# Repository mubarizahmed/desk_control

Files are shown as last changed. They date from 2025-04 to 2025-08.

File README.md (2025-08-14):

# desk-control

This is a simple physical widget that sits on your desk and allows you to perform some basic productivity tasks. It works independently of your computer or phone and hence, _in theory_, it should help you focus on your work. It is a work in progress and I will be adding more features as I go along.

<div align="center" style="display: flex; justify-content: center; align-items: center;">
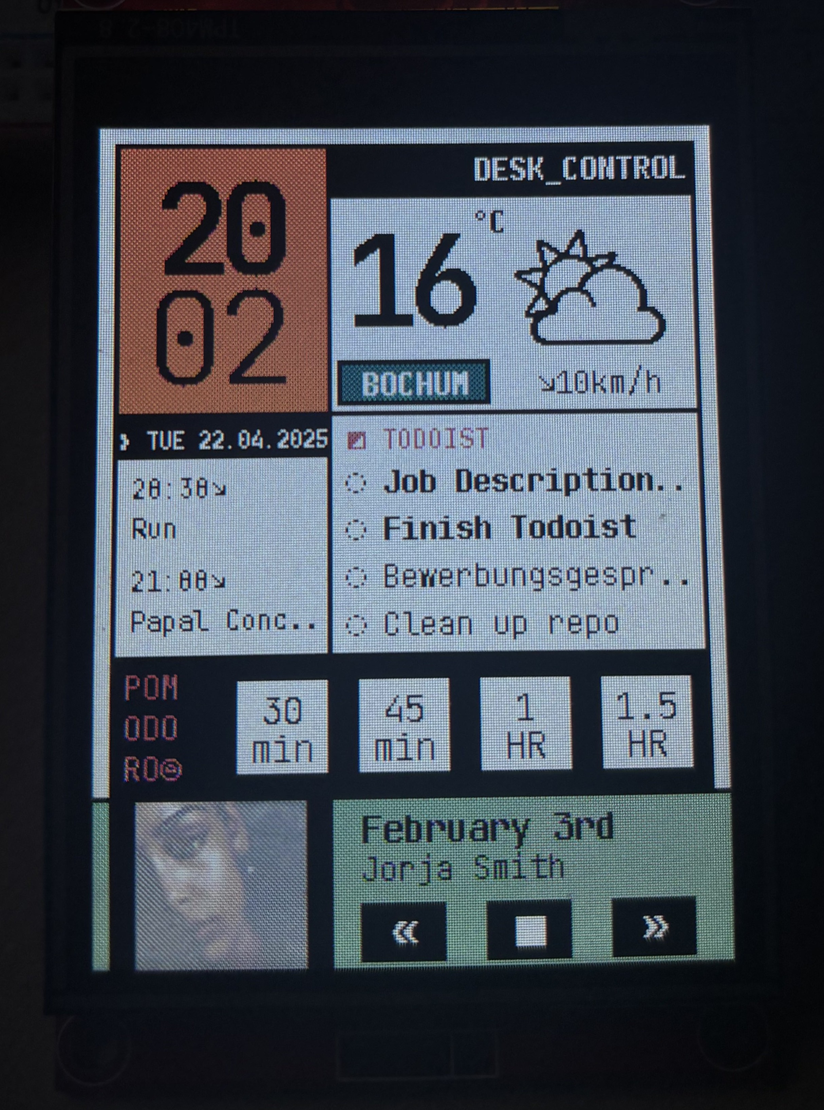
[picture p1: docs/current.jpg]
Actual UI
  
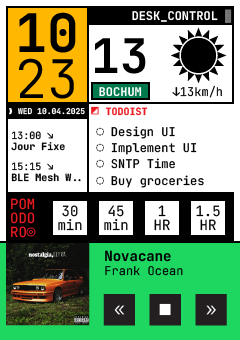
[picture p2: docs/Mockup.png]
Mock UI
  
</div>

## Features

- **Current Time** - Displays the current time in a 24-hour format.
- **Weather** - Displays the current temperature, wind, and weather condition (sunny, cloudy, etc.) for a given location.
- **Pomodoro Timer** - A simple timer that helps you focus on your work for a some template amount of time and then take a break. Current implementation is 25 minutes of work and 5 minutes of break. You can change this in the code.
- **Calendar** - Displays the current date and the next 2 events from your Google Calendar. You need to set up a Google script to get the events from your calendar. See the [Google Calendar Setup](#google-calendar-setup) section below.

- **Spotify Control** - Control your Spotify playback (play, pause, next, previous) from the widget.

- **Todoist Integration** - View and complete your upcoming tasks from Todoist.

- **PCB Design** - Single PCB design that can be printed on PCBWay or JLCPCB.

## Planned Features

- **Housing** - 3D printed housing for the PCB and screen.

- **Sensor Integration** - Add more sensors to the project - maybe a temperature sensor, humidity sensor, etc. to get more data from the environment.

- **Widget Details** - Widgets will be clickable and will show more details about the current state. For example, the weather widget will show the hourly forecast for the next 24 hours, the calendar widget will show the events for the next week, etc.

## Hardware Setup (Work in Progress)

The hardware setup is a work in progress. I will be updating this section as I go along. Currently, the hardware setup is:

- **Microcontroller** - ESP32-DevKitC-v4
- **Display** - 2.4" TFT LCD (ILI9341) with SPI interface
- **Rotary Encoder** - KY-040 rotary encoder with push button.

A custom PCB has been designed but not yet tested. The schematic and KiCAD project files are available in the `eda` folder.

<div align="center">
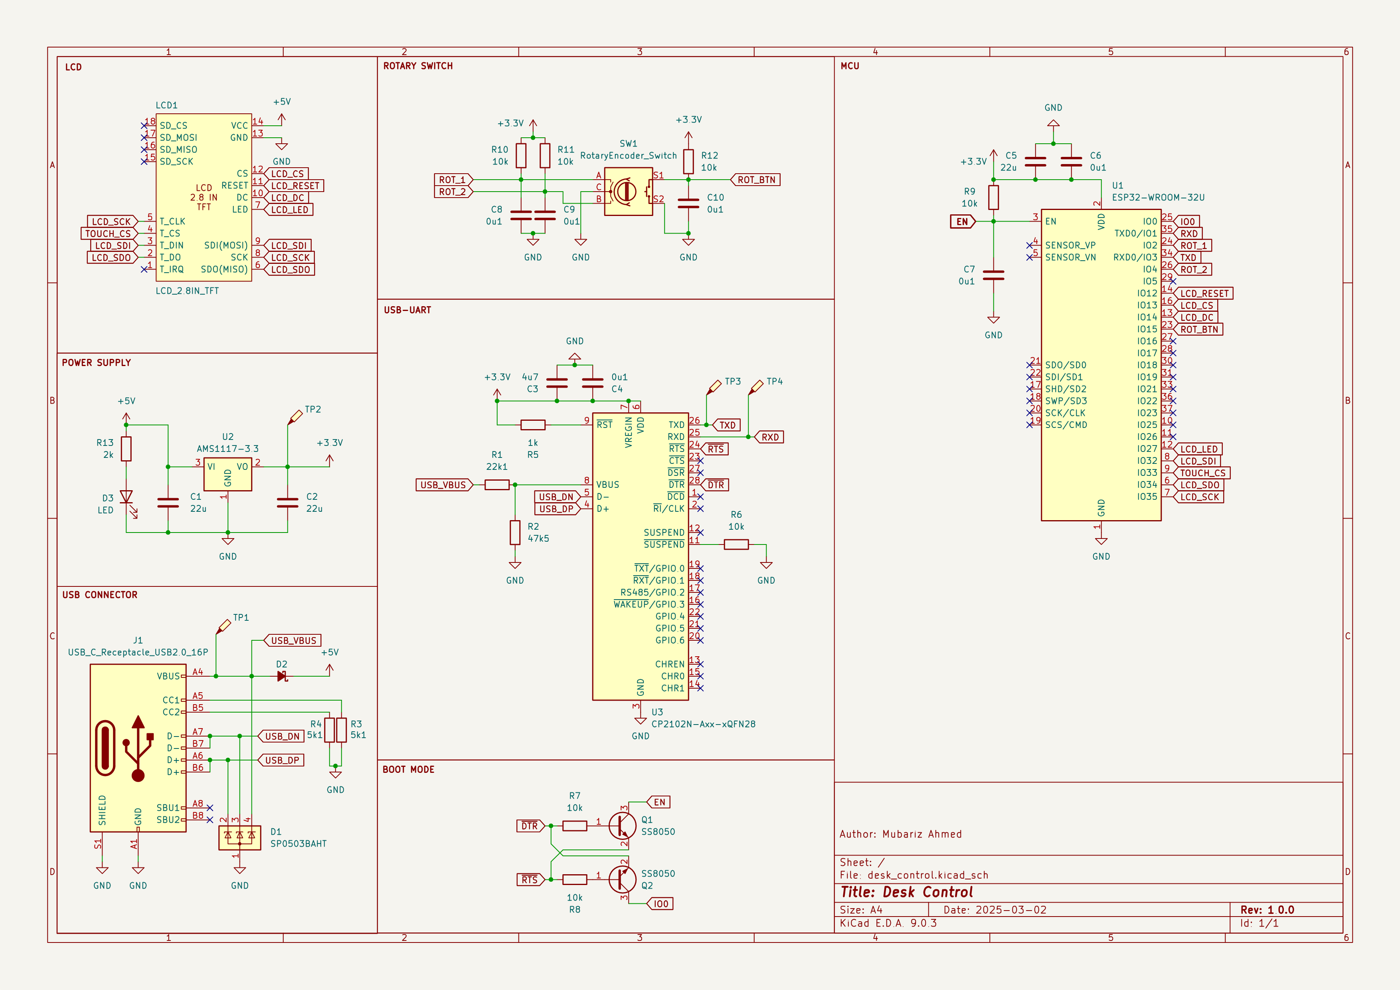
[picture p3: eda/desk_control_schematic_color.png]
Schematic
  
</div>

[Schematic](eda/desk_control_schematic_color.png)

<div align="center" style="display: flex; justify-content: center; align-items: center;">
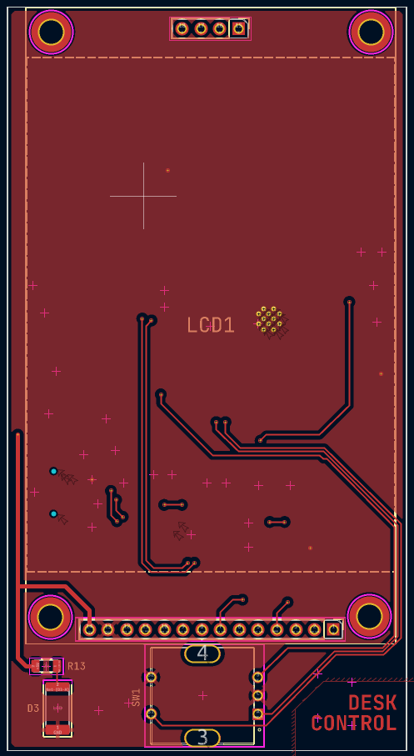
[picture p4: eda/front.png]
PCB Front
  
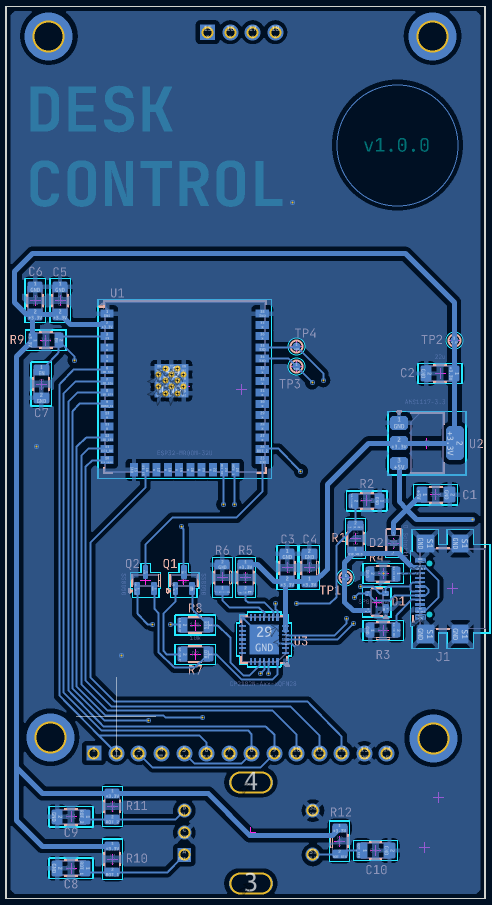
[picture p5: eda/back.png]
PCB Back
  
</div>

[PCB Front](eda/front.png) | [PCB Back](eda/back.png)

[KiCAD Project](eda/desk_control)

Pin definitions are given in [here](/main/pin_definitions.h).

## Software Setup

ESP IDF is used to program the ESP32. The project can be configured using `idf.py menuconfig`. The following configuration options are most relevant:

- **ESP_WIFI_SSID** - The SSID of the Wi-Fi network to connect to.
- **ESP_WIFI_PASSWORD** - The password of the Wi-Fi network to connect to.
- **CALENDAR_URL** - The URL of the Google script that returns the events from your calendar.

## Mock UI

The mock UI is a simple representation of what the final UI will look like. It is not a final design and will be updated as I go along. The current design is a simple grid layout with a monotype font which makes absolute positioning of the elements easy.

<div align="center">
  Mock UI
</div>

## Progress

The project is being prototyped on a breadboard and the hardware setup is a work in progress. The software is being developed in parallel. The current status of the project is shown below:

<div align="center">
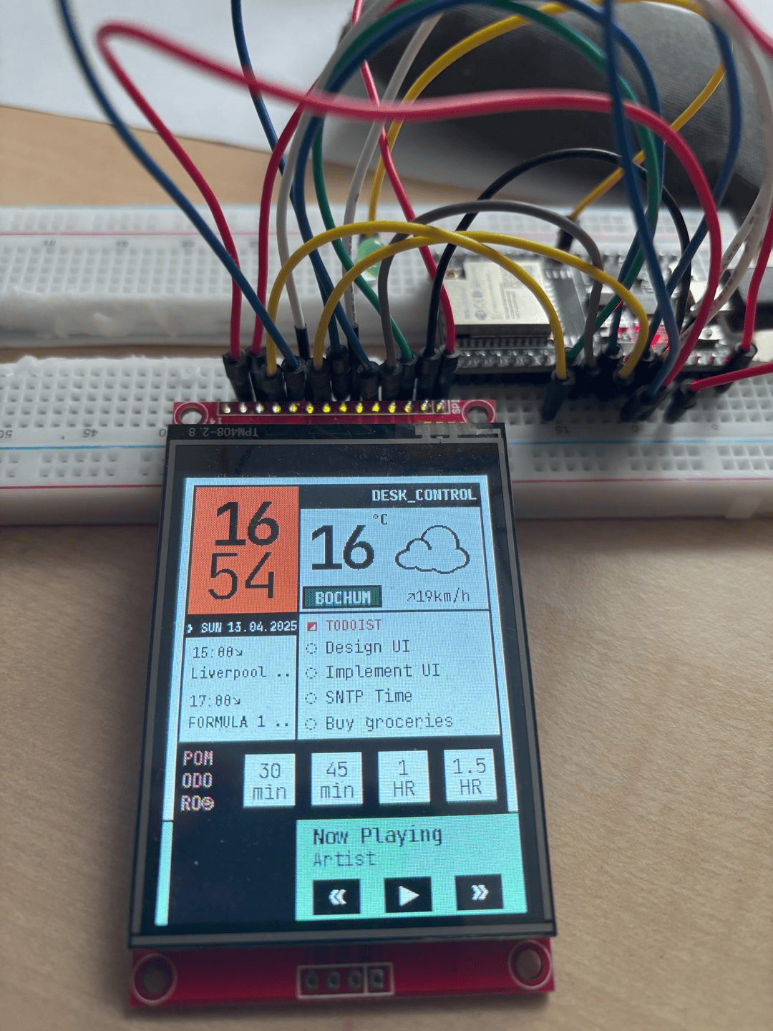
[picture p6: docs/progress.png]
Progress
  
</div>

## Google Calendar Setup

To get the events from your Google Calendar, you need to set up a Google script that will fetch the events and return them in a JSON format. The script should be deployed as a web app and the URL should be added to the code. The following steps will help you set up the Google script:

1. Go to [Google Apps Script](https://script.google.com/) and create a new project.
2. Copy and paste the code from this (file)[https://github.com/mubarizahmed/desk_control/blob/main/other/calendar.gs] into the script editor
3. Save the project and give it a name.
4. Click on the `Deploy` button and select `New deployment`.
5. Select `Web app` and give it a name.
6. Select `Anyone` under `Who has access` and click on `Deploy`.
7. Authorize the script to access your Google Calendar.
8. Copy the URL of the web app and paste it in the code where it says `CALENDAR_URL`.
9. Save the code and run the script to test it. You should see the events from your calendar in the JSON format.

Thanks to this [blog post](https://www.instructables.com/E-Ink-Family-Calendar-Using-ESP32/) for the idea and the code to get the events from the Google Calendar. The code has been modified to fit the needs of this project.

## Acknowledgements

Thanks to [wttr.in](https://wttr.in/) for the weather API and [Google Calendar API](https://developers.google.com/calendar) for the calendar API.

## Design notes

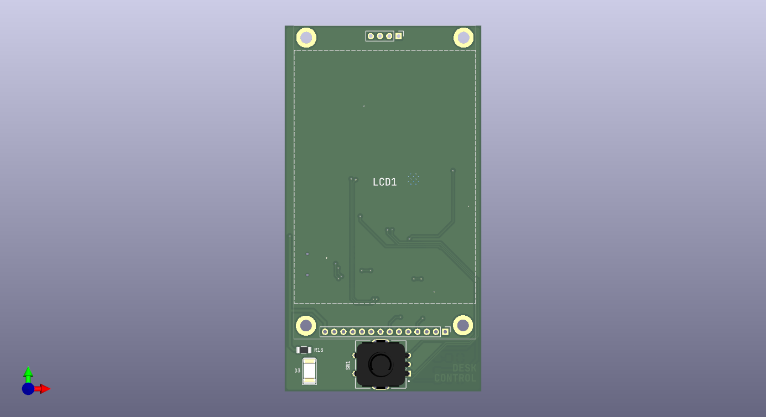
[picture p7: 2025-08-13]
eda/desk_control_f2.png

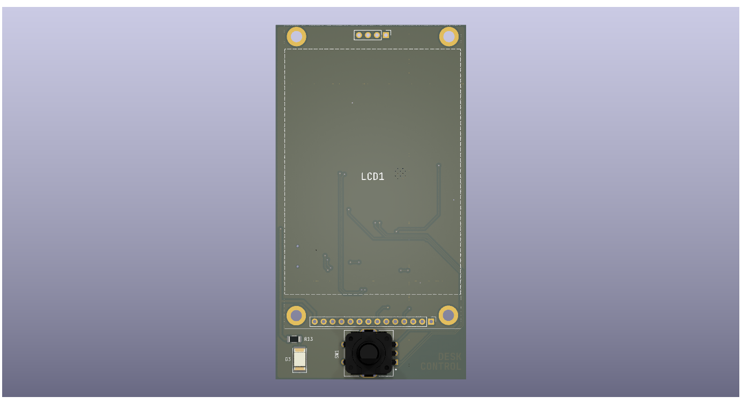
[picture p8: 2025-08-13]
eda/desk_control_f.png

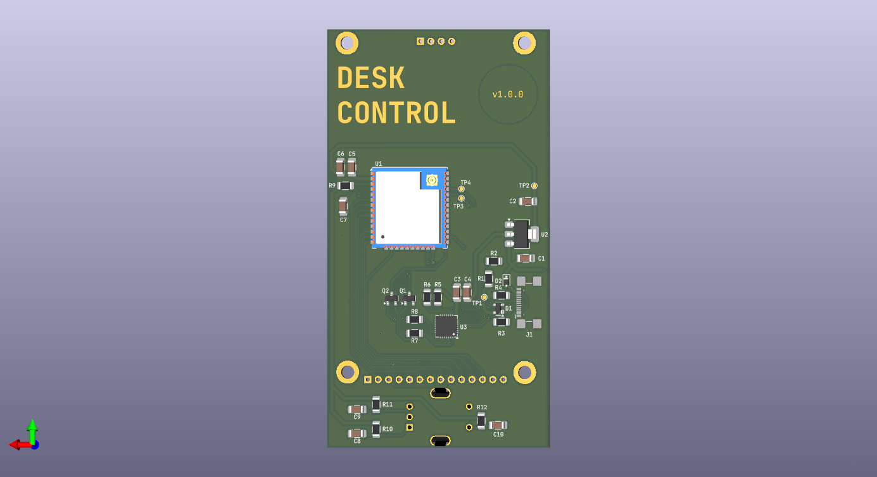
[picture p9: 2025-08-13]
eda/desk_control_b2.png

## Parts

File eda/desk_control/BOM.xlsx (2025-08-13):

Reference | Qty | Value | DNP | Exclude from BOM | Exclude from Board | Footprint | Datasheet
C1,C2,C5 | 3 | 22u |  |  |  | Capacitor_SMD:C_1206_3216Metric_Pad1.33x1.80mm_HandSolder | ~
C3 | 1 | 4u7 |  |  |  | Capacitor_SMD:C_1206_3216Metric_Pad1.33x1.80mm_HandSolder | ~
C4,C6,C7,C8,C9,C10 | 6 | 0u1 |  |  |  | Capacitor_SMD:C_1206_3216Metric_Pad1.33x1.80mm_HandSolder | ~
D1 | 1 | SP0503BAHT |  |  |  | Package_TO_SOT_SMD:SOT-143 | http://www.littelfuse.com/~/media/files/littelfuse/technical%20resources/documents/data%20sheets/sp05xxba.pdf
D2 | 1 | D_Schottky_Small_Filled |  |  |  | Diode_SMD:D_SOD-323F | ~
D3 | 1 | LED |  |  |  | LED_SMD:LED_2512_6332Metric | ~
J1 | 1 | USB_C_Receptacle_USB2.0_16P |  |  |  | Connector_USB:USB_C_Receptacle_GCT_USB4110 | https://www.usb.org/sites/default/files/documents/usb_type-c.zip
LCD1 | 1 | LCD_2.8IN_TFT |  |  |  | Custom:LCD_2.8_TFT
Q1,Q2 | 2 | SS8050 |  |  |  | Package_TO_SOT_SMD:SOT-23 | http://www.secosgmbh.com/datasheet/products/SSMPTransistor/SOT-23/SS8050.pdf
R1 | 1 | 22k1 |  |  |  | Resistor_SMD:R_1206_3216Metric | ~
R2 | 1 | 47k5 |  |  |  | Resistor_SMD:R_1206_3216Metric | ~
R3,R4 | 2 | 5k1 |  |  |  | Resistor_SMD:R_1206_3216Metric | ~
R5 | 1 | 1k |  |  |  | Resistor_SMD:R_1206_3216Metric | ~
R6,R7,R8,R9,R10,R11,R12 | 7 | 10k |  |  |  | Resistor_SMD:R_1206_3216Metric | ~
R13 | 1 | 2k |  |  |  | Resistor_SMD:R_1206_3216Metric | ~
SW1 | 1 | RotaryEncoder_Switch |  |  |  | Custom:Bourns-PEC11R-4220F-S0024-0-0-0 | ~
TP1,TP2,TP3,TP4 | 4 | TestPoint_Probe |  |  |  | TestPoint:TestPoint_Pad_D1.0mm | ~
U1 | 1 | ESP32-WROOM-32U |  |  |  | RF_Module:ESP32-WROOM-32U | https://www.espressif.com/sites/default/files/documentation/esp32-wroom-32d_esp32-wroom-32u_datasheet_en.pdf
U2 | 1 | AMS1117-3.3 |  |  |  | Package_TO_SOT_SMD:SOT-223-3_TabPin2 | http://www.advanced-monolithic.com/pdf/ds1117.pdf
U3 | 1 | CP2102N-Axx-xQFN28 |  |  |  | Package_DFN_QFN:QFN-28-1EP_5x5mm_P0.5mm_EP3.35x3.35mm | https://www.silabs.com/documents/public/data-sheets/cp2102n-datasheet.pdf

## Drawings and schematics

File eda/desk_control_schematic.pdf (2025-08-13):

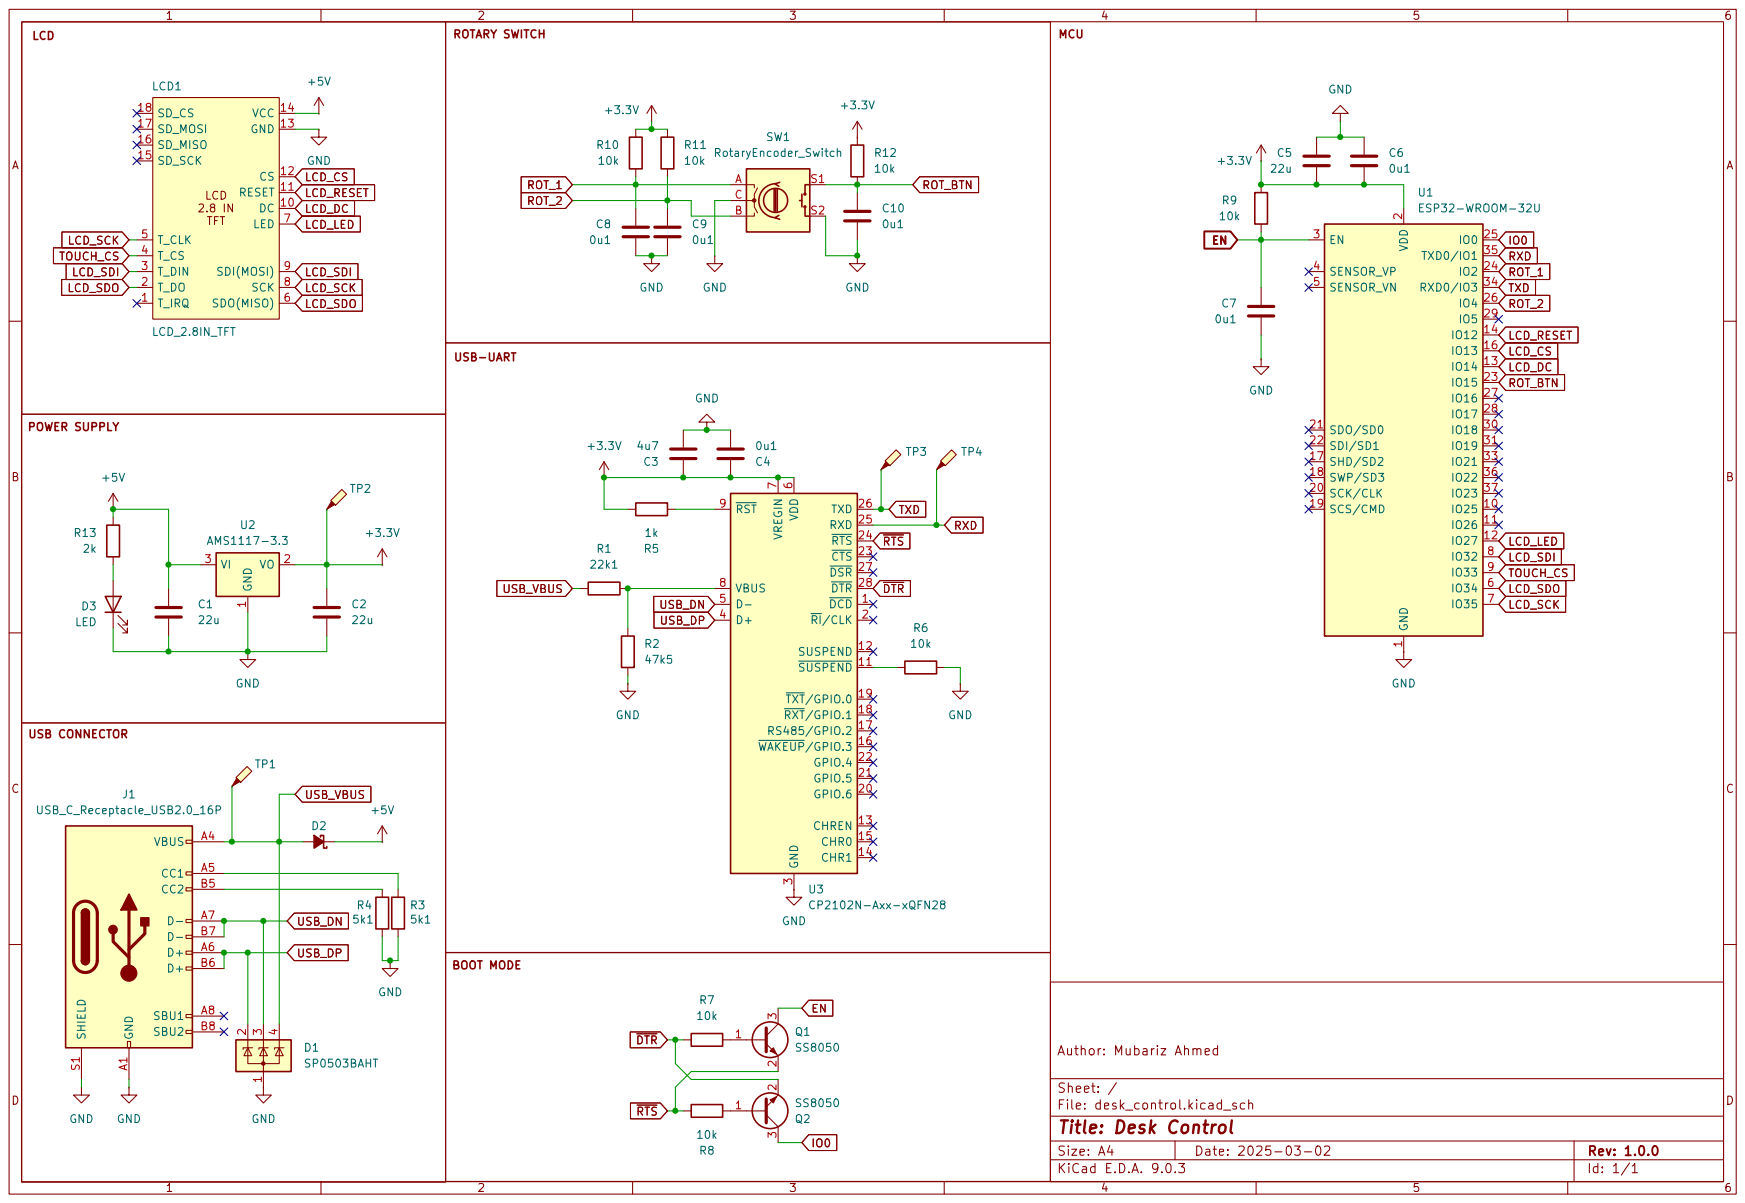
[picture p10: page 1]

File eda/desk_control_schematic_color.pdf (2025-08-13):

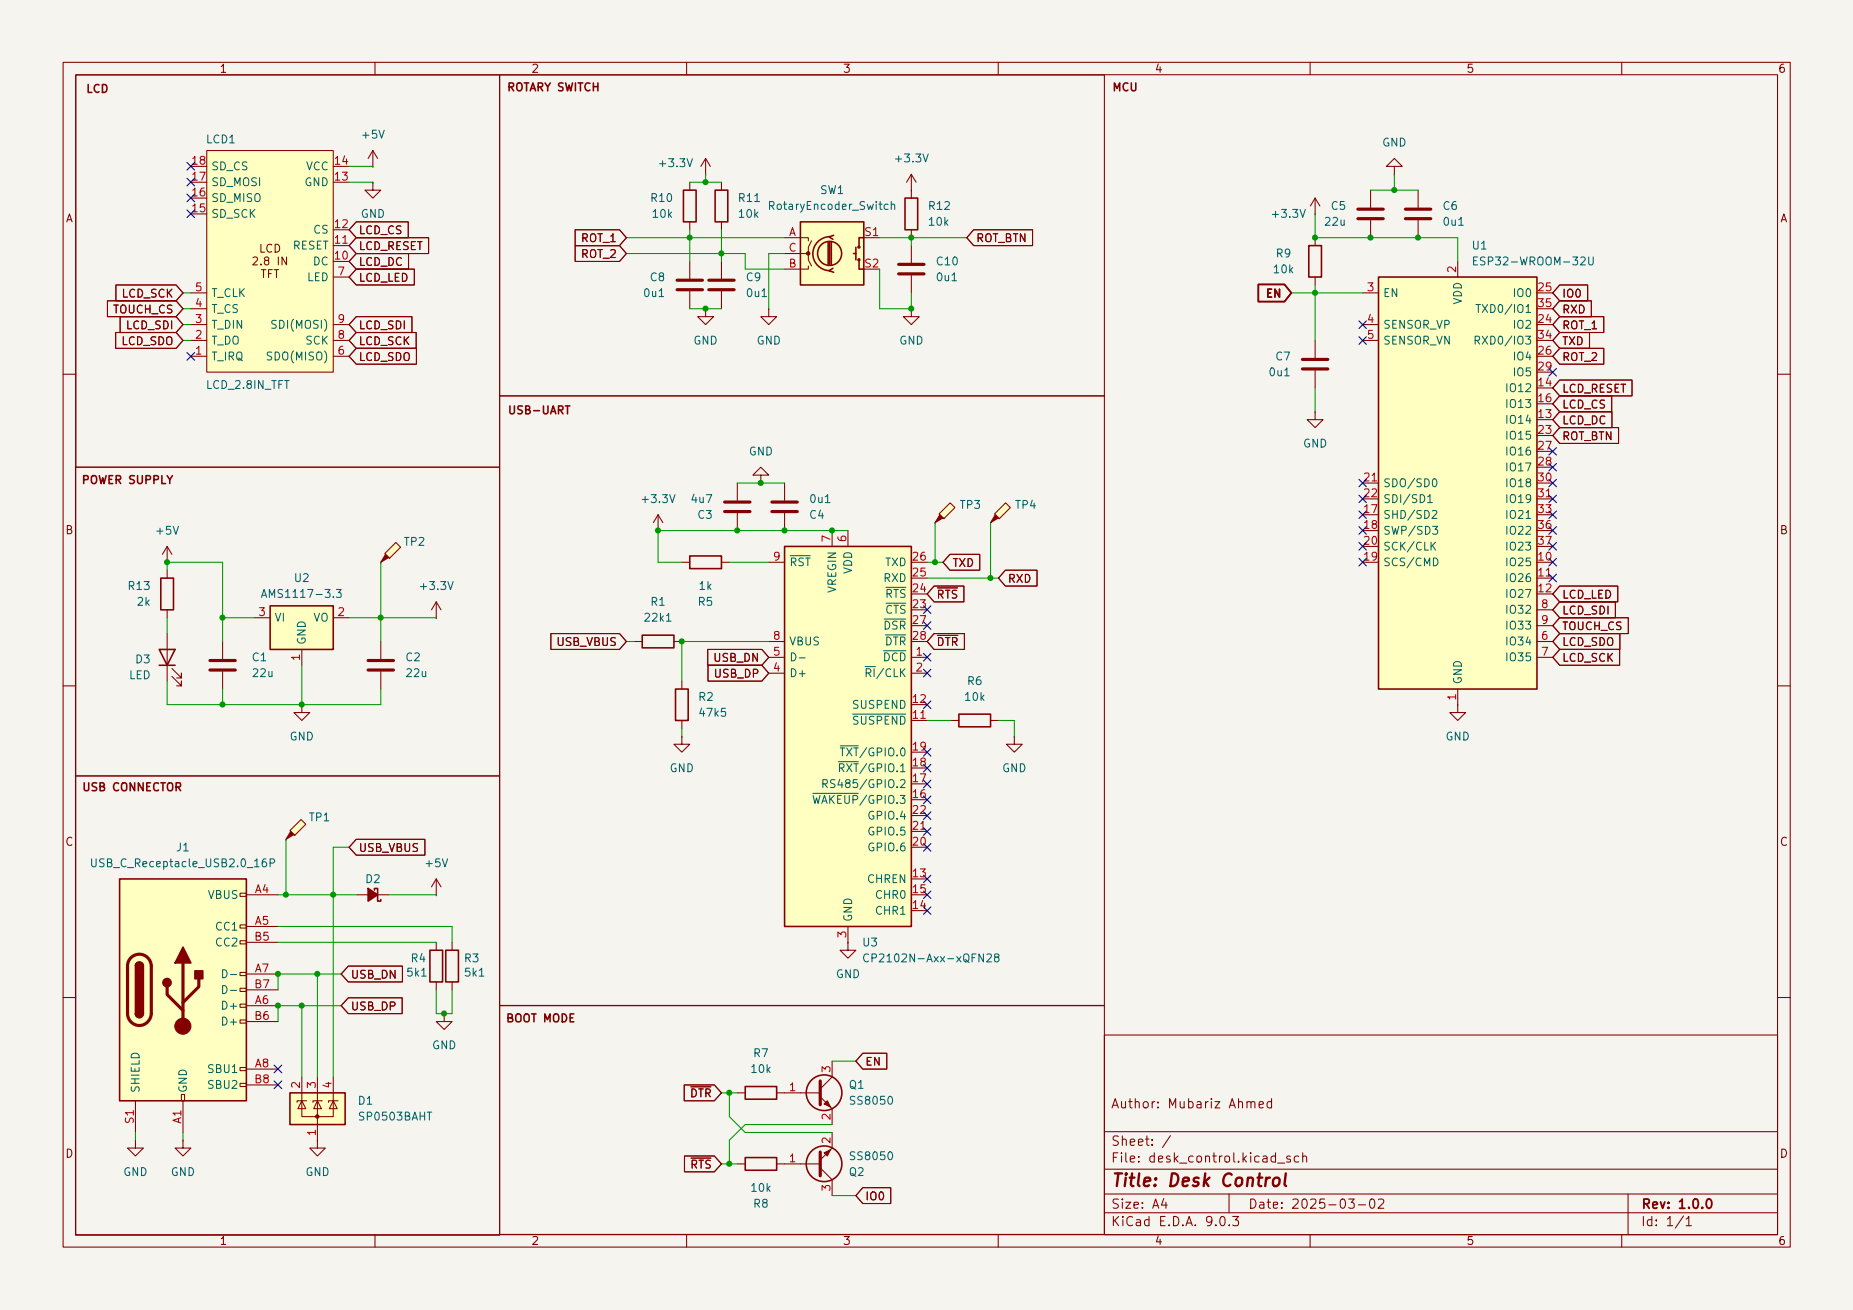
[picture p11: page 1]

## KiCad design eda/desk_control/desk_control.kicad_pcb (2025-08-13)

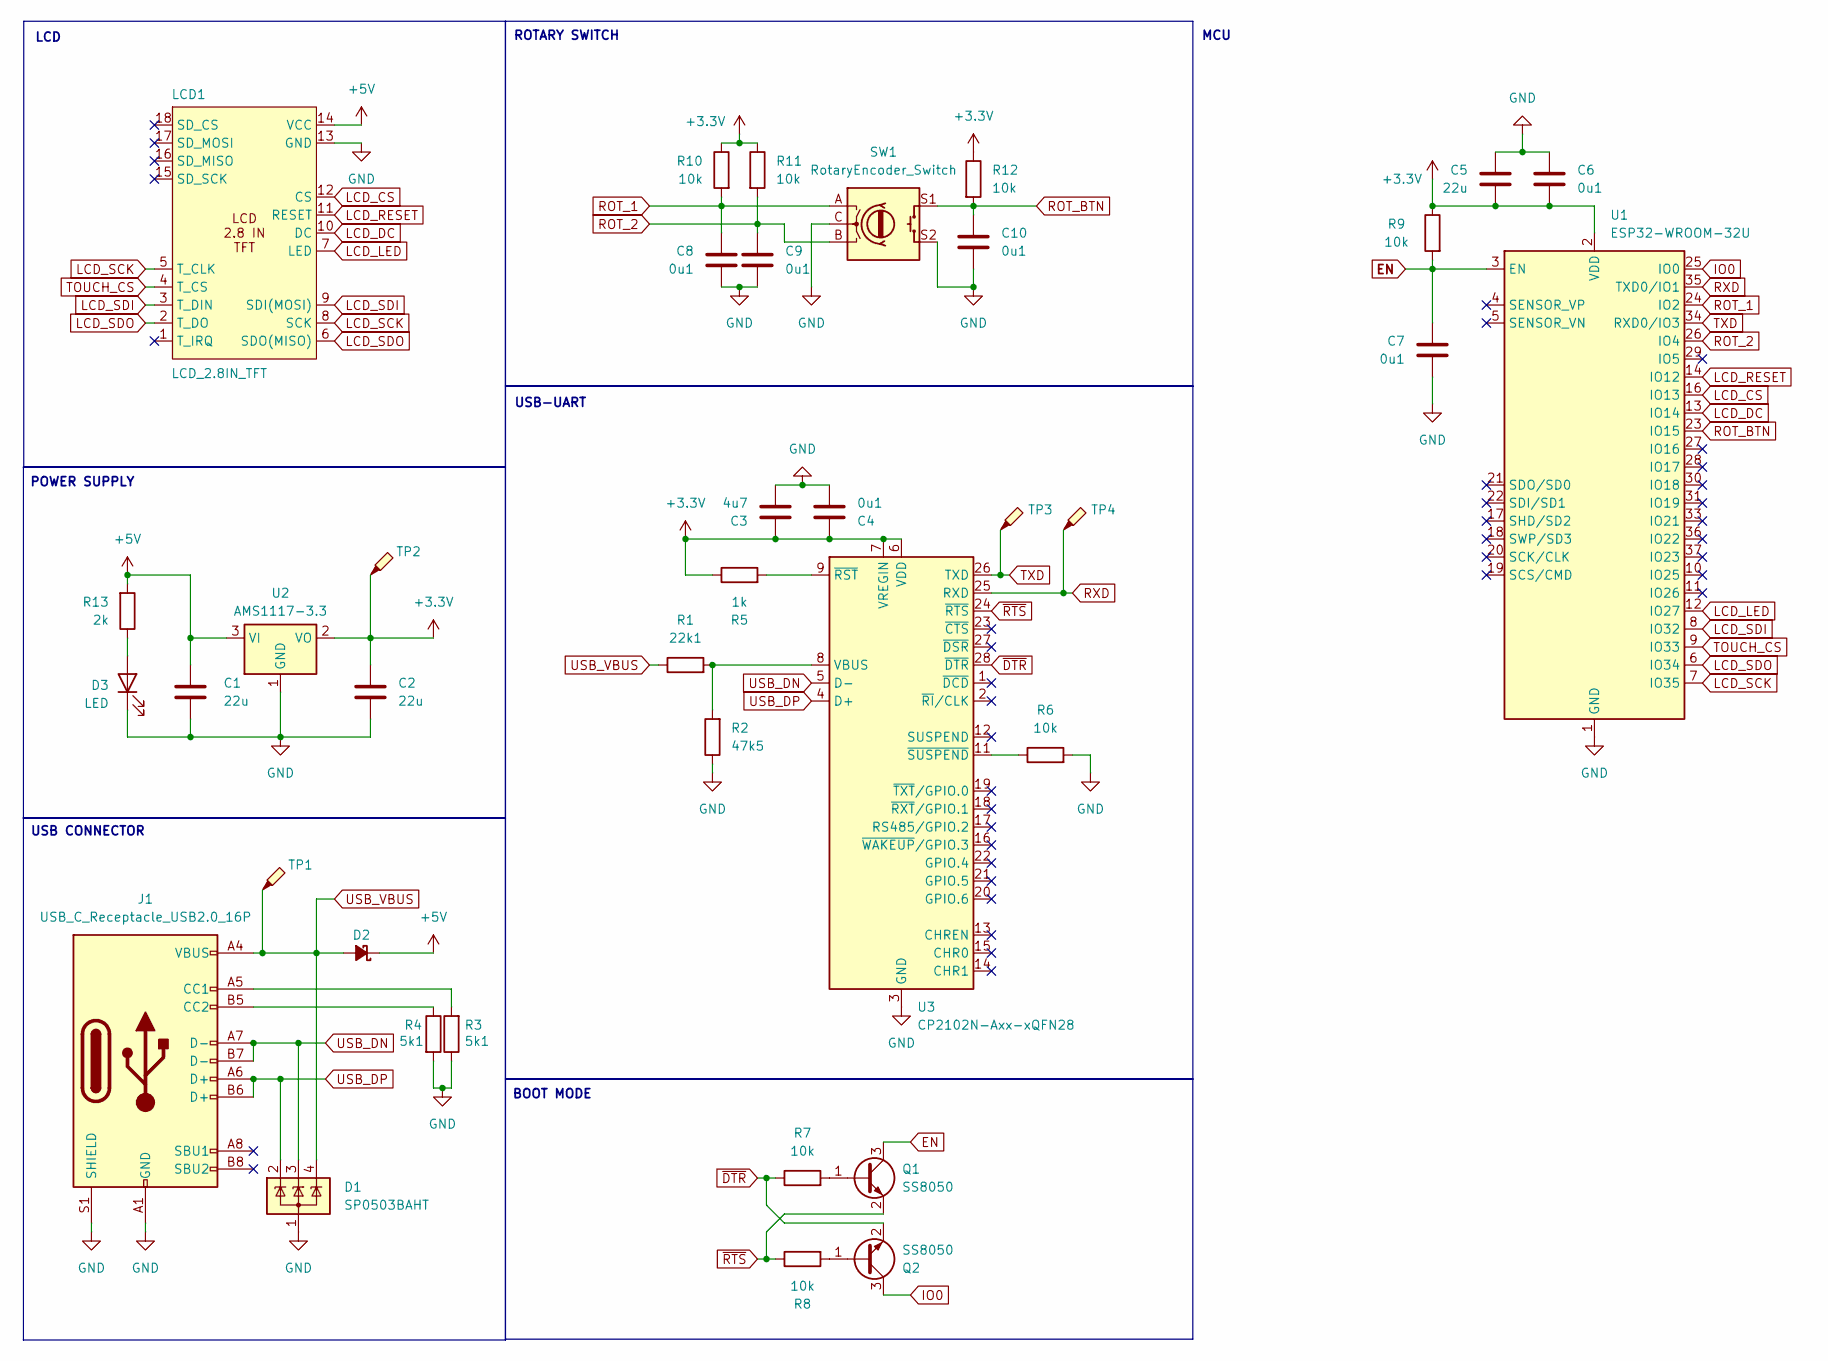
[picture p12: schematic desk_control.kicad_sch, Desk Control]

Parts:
C1, C2, C5: 22u; C_1206_3216Metric_Pad1.33x1.80mm_HandSolder
C3: 4u7; C_1206_3216Metric_Pad1.33x1.80mm_HandSolder
C4, C6, C7, C8, C9, C10: 0u1; C_1206_3216Metric_Pad1.33x1.80mm_HandSolder
D1: SP0503BAHT; SOT-143
D2: D_Schottky_Small_Filled; D_SOD-323F
D3: LED; LED_2512_6332Metric
J1: USB_C_Receptacle_USB2.0_16P; USB_C_Receptacle_GCT_USB4110
LCD1: LCD_2.8IN_TFT; LCD_2.8_TFT
Q1, Q2: SS8050; SOT-23
R1: 22k1; R_1206_3216Metric
R2: 47k5; R_1206_3216Metric
R3, R4: 5k1; R_1206_3216Metric
R5: 1k; R_1206_3216Metric
R6, R7, R8, R9, R10, R11, R12: 10k; R_1206_3216Metric
R13: 2k; R_1206_3216Metric
SW1: RotaryEncoder_Switch; Bourns-PEC11R-4220F-S0024-0-0-0
TP1, TP2, TP3, TP4: TestPoint_Probe; TestPoint_Pad_D1.0mm
U1: ESP32-WROOM-32U
U2: AMS1117-3.3; SOT-223-3_TabPin2
U3: CP2102N-Axx-xQFN28; QFN-28-1EP_5x5mm_P0.5mm_EP3.35x3.35mm

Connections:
+3.3V: C2.1, C3.2, C4.1, C5.2, C6.2, R5.1, R9.1, R10.1, R11.1, R12.1, TP2.1, U1.2 (VDD), U2.2 (VO), U3.6 (VDD), U3.7 (VREGIN)
+5V: C1.1, D2.1 (K), LCD1.14 (VCC), R13.2, U2.3 (VI)
EN: C7.1, Q1.3 (C), R9.2, U1.3 (EN)
GND: C1.2, C2.2, C3.1, C4.2, C5.1, C6.1, C7.2, C8.2, C9.2, C10.2, D1.1 (A), D3.1 (K), J1.A1 (GND), J1.A12 (GND), J1.B1 (GND), J1.B12 (GND), J1.S1 (SHIELD), LCD1.13 (GND), R2.1, R3.1, R4.2, R6.2, SW1.C, SW1.S2, U1.1 (GND), U1.15 (GND), U1.38 (GND), U1.39 (GND), U2.1 (GND), U3.3 (GND), U3.29 (GND)
IO0: Q2.3 (C), U1.25 (IO0)
LCD_CS: LCD1.12 (CS), U1.16 (IO13)
LCD_DC: LCD1.10 (DC), U1.13 (IO14)
LCD_LED: LCD1.7 (LED), U1.12 (IO27)
LCD_RESET: LCD1.11 (RESET), U1.14 (IO12)
LCD_SCK: LCD1.5 (T_CLK), LCD1.8 (SCK), U1.7 (IO35)
LCD_SDI: LCD1.3 (T_DIN), LCD1.9 (SDI(MOSI)), U1.8 (IO32)
LCD_SDO: LCD1.2 (T_DO), LCD1.6 (SDO(MISO)), U1.6 (IO34)
unnamed: D3.2 (A), R13.1
unnamed: J1.A5 (CC1), R3.2
unnamed: J1.B5 (CC2), R4.1
unnamed: Q1.1 (B), R7.2
unnamed: Q2.1 (B), R8.2
unnamed: R1.2, R2.2, U3.8 (VBUS)
unnamed: R5.2, U3.9 (~RST)
unnamed: R6.1, U3.11 (~SUSPEND)
ROT_1: C8.1, R10.2, SW1.A, U1.24 (IO2)
ROT_2: C9.1, R11.2, SW1.B, U1.26 (IO4)
ROT_BTN: C10.1, R12.2, SW1.S1, U1.23 (IO15)
RXD: TP4.1, U1.35 (TXD0/IO1), U3.25 (RXD)
TOUCH_CS: LCD1.4 (T_CS), U1.9 (IO33)
TXD: TP3.1, U1.34 (RXD0/IO3), U3.26 (TXD)
USB_DN: D1.3 (K), J1.A7 (D-), J1.B7 (D-), U3.5 (D-)
USB_DP: D1.2 (K), J1.A6 (D+), J1.B6 (D+), U3.4 (D+)
USB_VBUS: D1.4 (K), D2.2 (A), J1.A4 (VBUS), J1.A9 (VBUS), J1.B4 (VBUS), J1.B9 (VBUS), R1.1, TP1.1
~DTR: Q2.2 (E), R7.1, U3.28 (~DTR)
~RTS: Q1.2 (E), R8.1, U3.24 (~RTS)

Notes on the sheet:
LCD
USB-UART
USB CONNECTOR
BOOT MODE
POWER SUPPLY
ROTARY SWITCH
MCU

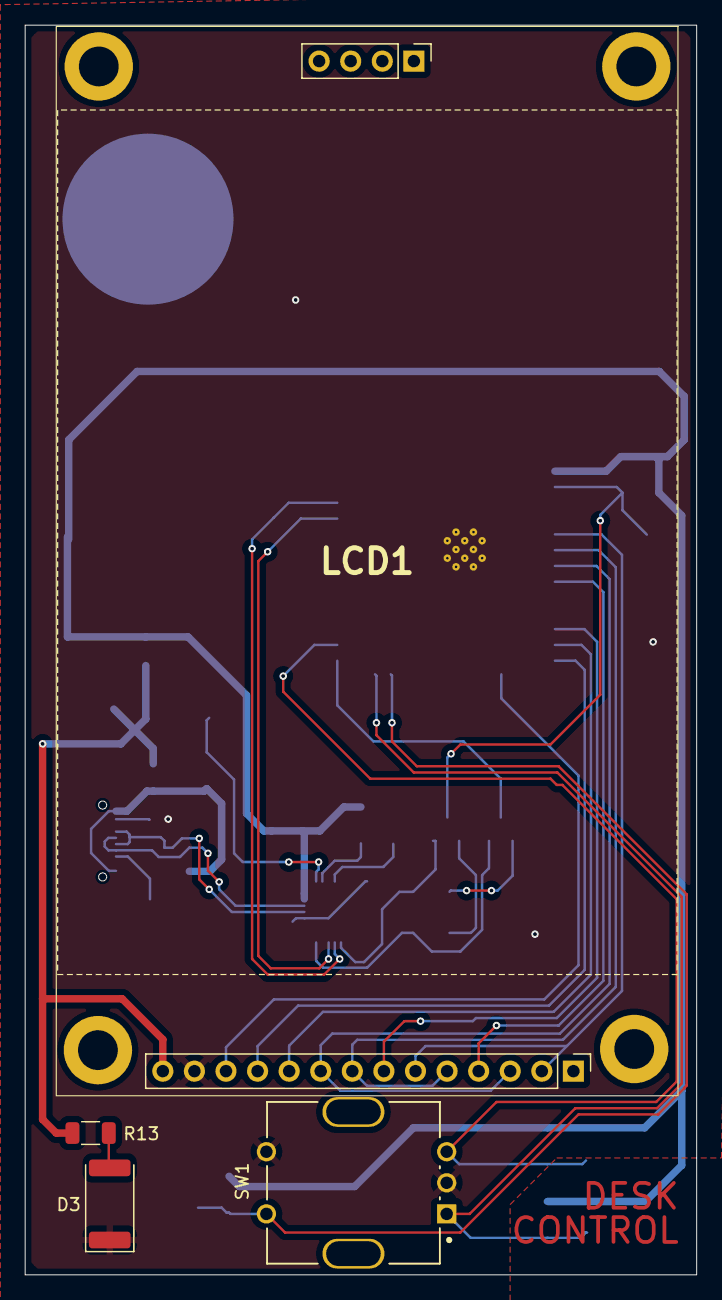
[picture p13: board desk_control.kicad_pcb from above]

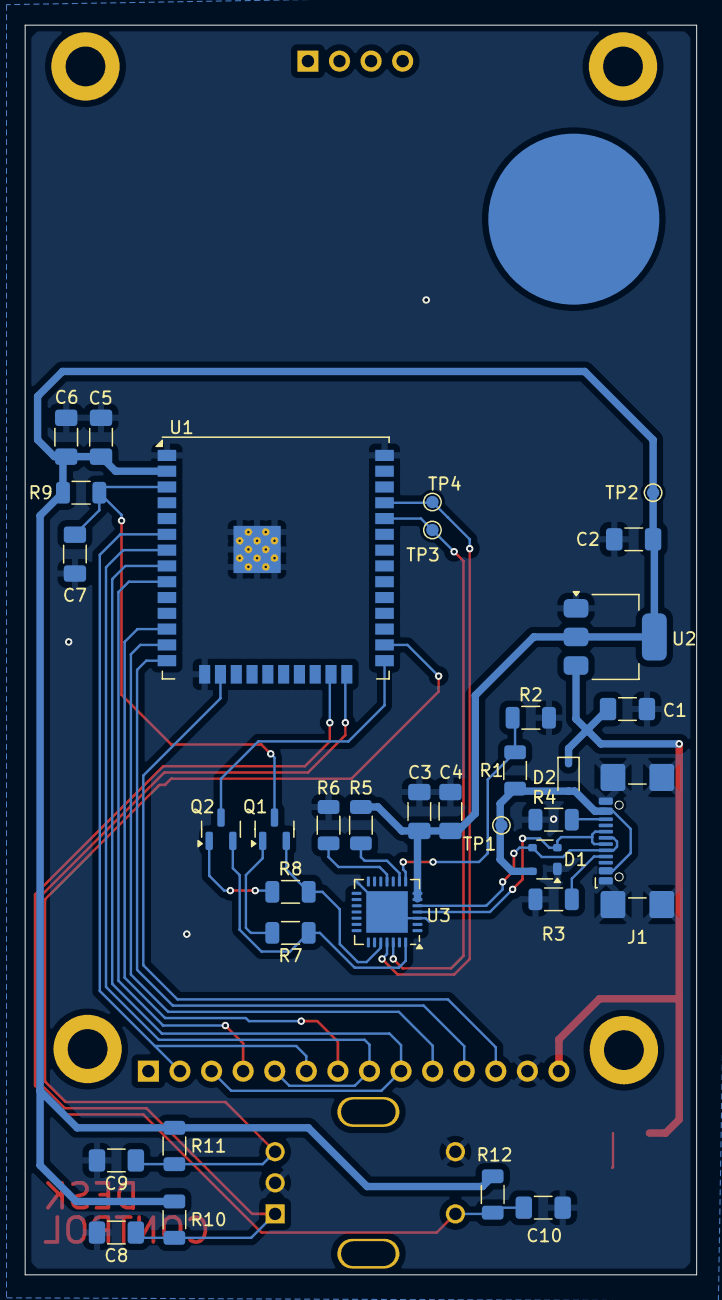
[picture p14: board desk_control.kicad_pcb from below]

Board: 2 copper layers, 54.0 x 100.5 mm, 38 parts (34 on the bottom side), 31 nets.

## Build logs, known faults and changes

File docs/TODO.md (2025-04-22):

# TODO

-[ ] extract fn heap memory stats

-[ ] spotifycontext drilling

-[ ] tests

-[ ] spotify refresh token on unauthorized

-[x] fix apostrophe in font

-[ ] look into jpeg decode

-[ ] Spotify start delay

-[ ] Calendar clear empty events

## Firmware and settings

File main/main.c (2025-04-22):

/**
 * @file main.c
 * @author Mubariz Ahmed (mubariz@mubariz.me)
 * @brief Application entry point.
 * @version 0.1
 * @date 2025-04-09
 *
 */

/* ------------------------------------------------------ */
/*                        INCLUDES                        */
/* ------------------------------------------------------ */

#include "driver/gpio.h"
#include "esp_err.h"
#include "esp_log.h"
#include "esp_timer.h"
#include "freertos/FreeRTOS.h"
#include "freertos/task.h"
#include "mbedtls/platform.h"
#include "nvs_flash.h"
#include <stdio.h>
#include <sys/lock.h>
#include <sys/param.h>
#include <unistd.h>

#include "app_events.h"
#include "calendar_serv.h"
#include "display_manager.h"
#include "esp_event.h"
#include "pin_definitions.h"
#include "pomodoro.h"
#include "spotify_serv.h"
#include "time_serv.h"
#include "todoist_serv.h"
#include "ui.h"
#include "weather_serv.h"
#include "wifi_manager.h"

/* ------------------------------------------------------ */
/*                    PRIVATE VARIABLES                   */
/* ------------------------------------------------------ */

static const char *TAG = "MAIN";

/* ------------------------------------------------------ */
/*                    PRIVATE FUNCTIONS                   */
/* ------------------------------------------------------ */

/**
 * @brief Custom memory allocation function for mbedtls.
 *
 * @param n Number of elements to allocate.
 * @param size Size of each element.
 * @return Pointer to the allocated memory.
 */
void *my_calloc(size_t n, size_t size) {
    return heap_caps_calloc(n, size, MALLOC_CAP_INTERNAL | MALLOC_CAP_8BIT);
}

/**
 * @brief Main application entry point.
 *
 */
void app_main(void) {

    app_events_init();
    spotify_event_group = xEventGroupCreate();

    // Initialize Display and LVGL
    display_manager_init();

    // Initialize NVS
    esp_err_t ret = nvs_flash_init();

    if (ret == ESP_ERR_NVS_NO_FREE_PAGES || ret == ESP_ERR_NVS_NEW_VERSION_FOUND) {
        ESP_LOGE(TAG, "NVS flash init failed: %s", esp_err_to_name(ret));
        ESP_LOGI(TAG, "Erasing NVS flash and reinitializing");
        ESP_ERROR_CHECK(nvs_flash_erase());
        ret = nvs_flash_init();
    }
    ESP_ERROR_CHECK(ret);

    // check if NVS is initialized
    nvs_handle_t my_handle;
    ret = nvs_open("storage", NVS_READWRITE, &my_handle);
    if (ret != ESP_OK) {
        printf("Error (%s) opening NVS handle!\n", esp_err_to_name(ret));
        ESP_ERROR_CHECK(ret);
    }
    ESP_LOGI(TAG, "NVS handle opened successfully");
    nvs_close(my_handle);

    mbedtls_platform_set_calloc_free(my_calloc, free);

    // esp_log_level_set("wifi", ESP_LOG_VERBOSE);

    esp_log_level_set("MEMORY", ESP_LOG_VERBOSE);
    esp_log_level_set("STACK", ESP_LOG_VERBOSE);

    wifi_init_sta();

    while (1) {
        // Wait for WiFi to connect
        if (wifi_connected == 1) {
            break;
        }
        vTaskDelay(pdMS_TO_TICKS(1000)); // 1 second delay
    }

    // create new task for pomodoro
    xTaskCreate(&pomodoro_task, "pomodoro_task", 1024 * 1, NULL, 4, NULL);

    // create task to get time and keep widget updated
    xTaskCreate(&time_task, "time_task", 1024 * 5, NULL, 3, NULL);

    EventBits_t uxBits = xEventGroupWaitBits(
        app_event_group,
        TIME_SET_EVENT,
        pdTRUE,       // Clear the bits before returning
        pdFALSE,      // Wait for any bit to be set
        portMAX_DELAY // Wait indefinitely
    );

    // create new task to fetch data
    xTaskCreate(&weather_task, "weather_task", 1024 * 10, NULL, 2, NULL);

    uxBits = xEventGroupWaitBits(
        app_event_group,
        WEATHER_SET_EVENT,
        pdTRUE,       // Clear the bits before returning
        pdFALSE,      // Wait for any bit to be set
        portMAX_DELAY // Wait indefinitely
    );

    // create new task for calendar
    xTaskCreate(&calendar_task, "calendar_task", 1024 * 10, NULL, 2, NULL);

    uxBits = xEventGroupWaitBits(
        app_event_group,
        CALENDAR_SET_EVENT,
        pdTRUE,       // Clear the bits before returning
        pdFALSE,      // Wait for any bit to be set
        portMAX_DELAY // Wait indefinitely
    );

    // esp_log_level_set("TODOIST_SERV", ESP_LOG_INFO); // Set log level to INFO for all components

    xTaskCreate(&todoist_task, "todoist_task", 1024 * 25, NULL, 3, NULL);

    uxBits = xEventGroupWaitBits(
        app_event_group,
        TODOIST_SET_EVENT,
        pdTRUE,       // Clear the bits before returning
        pdFALSE,      // Wait for any bit to be set
        portMAX_DELAY // Wait indefinitely
    );

    xTaskCreate(&spotify_task, "spotify_task", 1024 * 20, NULL, 3, NULL);

    while (1) {
        // print heap information
        size_t free_heap = esp_get_free_heap_size();
        size_t min_free_heap = esp_get_minimum_free_heap_size();
        ESP_LOGI(TAG, "Main heap: %zu bytes, Minimum free heap: %zu bytes", free_heap, min_free_heap);

        vTaskDelay(pdMS_TO_TICKS(30000)); // 1 minutes delay
    }
// #define DEBUG 1
#ifdef DEBUG_MAIN
    while (1) {

        // print system state every second
        TaskStatus_t *task_status_array = NULL;
        UBaseType_t task_count = uxTaskGetNumberOfTasks();
        task_status_array = (TaskStatus_t *)malloc(task_count * sizeof(TaskStatus_t));
        if (task_status_array == NULL) {
            ESP_LOGE(TAG, "Failed to allocate memory for task status array");
            continue;
        }
        UBaseType_t task_count_filled = uxTaskGetSystemState(task_status_array, task_count, NULL);
        for (UBaseType_t i = 0; i < task_count_filled; i++) {
            ESP_LOGI(TAG, "Task: %s, State: %d, Priority: %d , HighWatermark: %ld", task_status_array[i].pcTaskName,
                     task_status_array[i].eCurrentState, task_status_array[i].uxCurrentPriority, task_status_array[i].usStackHighWaterMark);
        }
        free(task_status_array);

        // print heap information
        size_t free_heap = esp_get_free_heap_size();
        size_t min_free_heap = esp_get_minimum_free_heap_size();
        ESP_LOGI(TAG, "Main heap: %zu bytes, Minimum free heap: %zu bytes", free_heap, min_free_heap);

        vTaskDelay(pdMS_TO_TICKS(60000)); // 1 minutes delay
    }
#endif
}

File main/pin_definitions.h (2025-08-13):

/**
 * @file pin_definitions.h
 * @author Mubariz Ahmed (mubariz@mubariz.me)
 * @brief Pin definitions for the ESP32-S3-DevKitC-1
 * @version 0.1
 * @date 2025-04-09
 *
 */

#ifndef PIN_DEFINITIONS_H
#define PIN_DEFINITIONS_H

/* ------------------------------------------------------ */
/*      GPIO pin definitions for the ESP32-DevKitC-v4     */
/* ------------------------------------------------------ */

#ifdef ESP32_DEVKIT_C_V4

#define PIN_NUM_SCLK 14     // GPIO14 (SCLK) - SPI2 Clock
#define PIN_NUM_MOSI 13     // GPIO13 (MOSI) - SPI2 Master Out Slave In
#define PIN_NUM_MISO 12     // GPIO12 (MISO) - SPI2 Master In Slave Out
#define PIN_NUM_LCD_DC 26   // GPIO26 (DC) - LCD Data/Command
#define PIN_NUM_LCD_RST 25  // GPIO25 (RST) - LCD Reset
#define PIN_NUM_LCD_CS 33   // GPIO33 (CS) - LCD Chip Select
#define PIN_NUM_BK_LIGHT 27 // GPIO27 (BL) - LCD Backlight
#define PIN_NUM_TOUCH_CS 32 // GPIO32 (CS) - Touch Chip Select

#endif // ESP32_DEVKIT_C_V4

/* ------------------------------------------------------ */
/*  GPIO pin definitions for the PCB with ESP32-WROOM32-U */
/* ------------------------------------------------------ */

#define PIN_NUM_SCLK 35     // GPIO35 (SCLK) - SPI Clock
#define PIN_NUM_MOSI 32     // GPIO32 (MOSI) - SPI Master Out Slave In
#define PIN_NUM_MISO 34     // GPIO34 (MISO) - SPI Master In Slave Out
#define PIN_NUM_LCD_DC 14   // GPIO14 (DC) - LCD Data/Command
#define PIN_NUM_LCD_RST 12  // GPIO12 (RST) - LCD Reset
#define PIN_NUM_LCD_CS 13   // GPIO13 (CS) - LCD Chip Select
#define PIN_NUM_BK_LIGHT 27 // GPIO27 (BL) - LCD Backlight
#define PIN_NUM_TOUCH_CS 13 // GPIO13 (CS) - Touch Chip Select

#define PIN_NUM_ROT_1 24   // GPIO24 (ROT1) - Rotary Encoder 1
#define PIN_NUM_ROT_2 26   // GPIO26 (ROT2) - Rotary Encoder 2
#define PIN_NUM_ROT_BTN 23 // GPIO23 (ROT_BTN) - Rotary Encoder Button

#endif // PIN_DEFINITIONS_H

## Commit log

2025-04-05 fix touch calibration
2025-04-10 update rotation, touch calibration, RGB mode
2025-04-10 fix memory leak time task
    [main.c]
2025-04-10 fix mutex for lvgl ui updates
    [display_manager.c, display_manager.h]
2025-04-11 add Spotify widget and refactor UI styles
    - Introduced a new Spotify widget to display current song and artist information.
    - Added buttons for previous, play/pause, and next actions within the Spotify widget.
    - Created a helper function `lv_obj_remove_border_paddin_scrollbar` to streamline the removal of borders and padding from UI objects.
    - Adjusted various UI elements for better alignment and spacing.
    - Updated font references to include additional sizes for better text rendering.
2025-04-19 add spotify get currently playing
2025-04-19 troubleshoot memory, wifi
    [component-size.csv]
2025-04-20 add spotify previous, pause, next on button
2025-04-20 fix next track
2025-04-22 fix random display initialization error
    [display_manager.c]
2025-08-13 add schematic, pcb design
    [BOM.xlsx, desk_control.kicad_pcb, desk_control.kicad_sch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]
